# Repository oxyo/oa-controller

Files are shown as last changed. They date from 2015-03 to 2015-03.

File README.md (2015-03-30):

## Open Automation Wireless End-Point controller  



This is an Arduino UNO compatible device with 5 relay control channels and Real time clock.
It uses [Ciseco XRF wireless RF radio UART serial data module][] to communicate with Open Automation Center
This is a main controlling element in Open Automation system.  

It can be easily used to control devices like Heaters, Coolers, Fans, Fan Coils, Lights or any other
environment control device in your home.
  
For more information please visit [openautomation.center](http://openautomation.center)

Licensed under [WTFPL license terms](http://www.wtfpl.net/)

[Ciseco XRF wireless RF radio UART serial data module]: http://shop.ciseco.co.uk/xrf-wireless-rf-radio-uart-serial-data-module-xbee-shaped/

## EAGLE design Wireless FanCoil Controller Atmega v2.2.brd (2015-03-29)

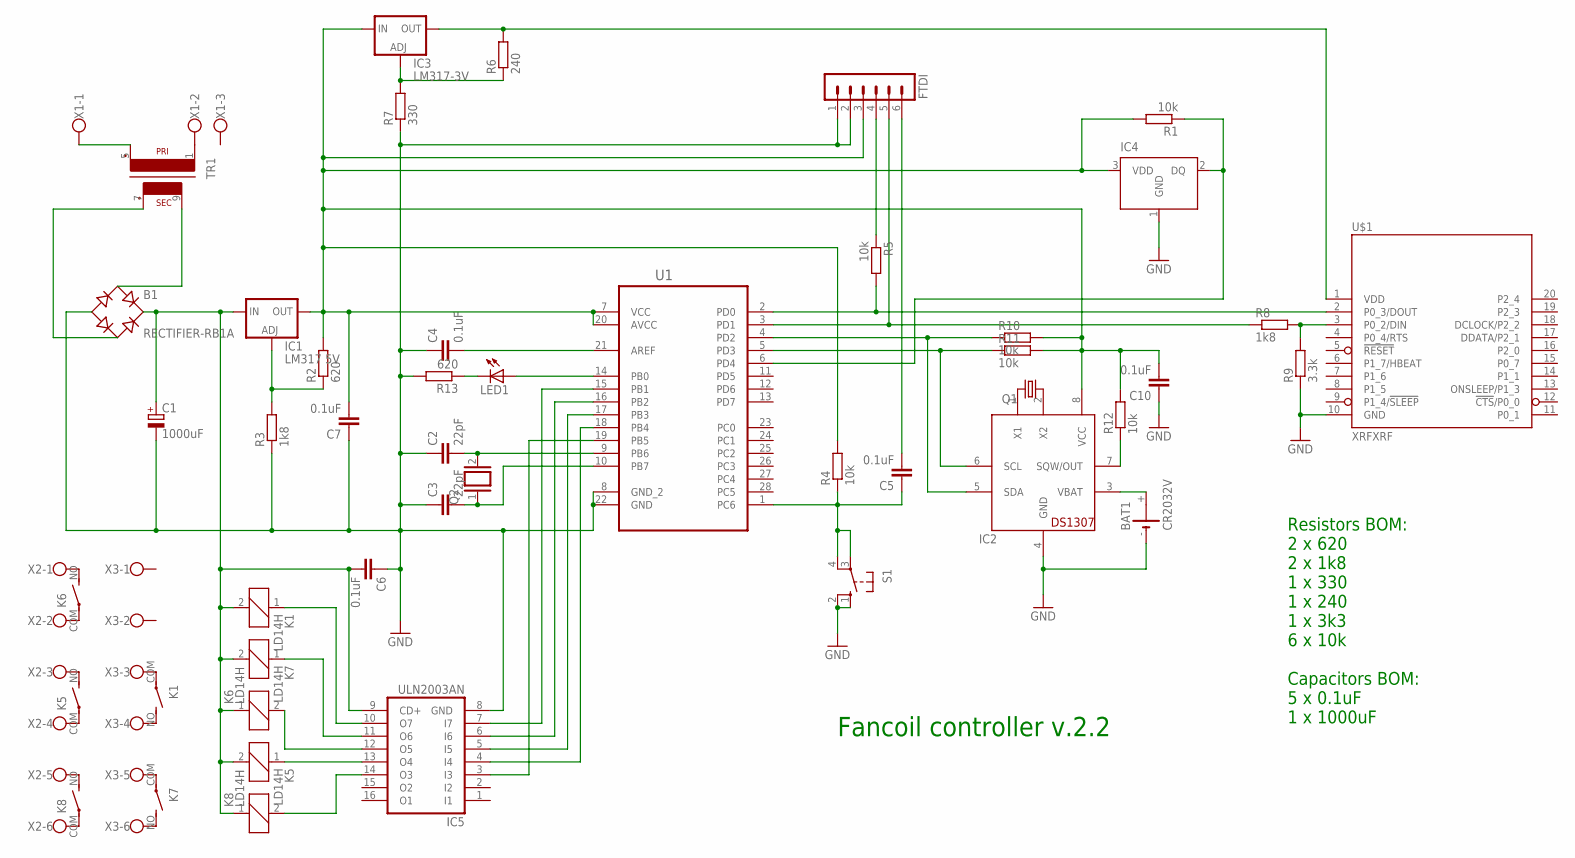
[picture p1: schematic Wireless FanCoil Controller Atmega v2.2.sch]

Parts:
B1: RECTIFIER-RB1A; RB1A
BAT1: CR2032V
C1: 1000uF; E5-10,5
C2, C3: 22pF; C025-025X050
C4, C5, C6, C7, C10: 0.1uF; C050-025X075
FTDI: MA06-1
IC1: LM317 5V; 317TS
IC2: DS1307; DIL08
IC3: LM317-3V; 317TS
IC4: DS1820; TO-92
IC5: ULN2003AN; DIL16
K1, K5, K6, K7, K8: LD14H; LD; MPN ALD112
LED1: LED3MM
Q1: CRYSTALTC26H; TC26H
Q2: XTAL/S; QS
R1, R4, R5, R10, R11, R12: 10k; 0207/5V
R2, R13: 620; 0207/5V
R3: 1k8; 0207/5V
R6: 240; 0207/5V
R7: 330; 0207/5V
R8: 1k8; 0207/12
R9: 3.3k; 0207/5V
S1: 10-XX; B3F-10XX
TR1: EI30-1
U1: ATMEGA328P-PU; DIP254P762X457-28
U$1: XRFXRF; XRF
X1: W237-103
X2, X3: W237-136

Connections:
GND: B1.-, BAT1.-, C1.-, C2.1, C3.1, C4.1, C6.1, C7.1, C10.1, FTDI.1, FTDI.2, IC2.4 (GND), IC4.1 (GND), IC5.8 (GND), R3.1, R7.1, R9.1, R13.2, S1.1 (S), S1.2 (S1), U1.8 (GND_2), U1.22 (GND), U$1.10 (GND)
LM317-5V: IC1.1 (ADJ), R2.1, R3.2
unnamed: C4.2, U1.21 (AREF)
unnamed: C5.2, FTDI.6
unnamed: IC2.2 (X2), Q1.1
unnamed: IC2.1 (X1), Q1.2
unnamed: IC5.10 (O7), K1.1
unnamed: IC3.2 (OUT), R6.2, U$1.1 (VDD)
unnamed: C7.2, C10.2, FTDI.3, IC1.2 (OUT), IC2.8 (VCC), IC3.3 (IN), IC4.3 (VDD), R1.2, R2.2, R4.2, R10.2, R11.2, R12.2, U1.7 (VCC), U1.20 (AVCC)
unnamed: TR1.1, X1.2
unnamed: TR1.5 (P2), X1.1
unnamed: B1.+, C1.+, C6.2, IC1.3 (IN), IC5.9 (CD+), K1.2, K5.2, K6.1, K7.2, K8.1
unnamed: B1.AC1, TR1.9 (S4)
unnamed: B1.AC2, TR1.7 (S3)
unnamed: C2.2, Q2.2, U1.9 (PB6)
unnamed: C3.2, Q2.1, U1.10 (PB7)
unnamed: C5.1, R4.1, S1.3, S1.4 (P1), U1.1 (PC6)
unnamed: FTDI.4, R5.1
unnamed: R5.2, U1.2 (PD0), U$1.2 (P0_3/DOUT)
unnamed: FTDI.5, R8.1, U1.3 (PD1)
unnamed: IC3.1 (ADJ), R6.1, R7.2
unnamed: IC2.5 (SDA), R10.1, U1.4 (PD2)
unnamed: R8.2, R9.2, U$1.3 (P0_2/DIN)
unnamed: IC2.6 (SCL), R11.1, U1.5 (PD3)
unnamed: IC2.7 (SQW/OUT), R12.1
unnamed: IC4.2 (DQ), R1.1, U1.6 (PD4)
unnamed: IC5.6 (I6), U1.16 (PB2)
unnamed: K8.NO (S), X2.5
unnamed: IC5.7 (I7), U1.15 (PB1)
unnamed: IC5.4 (I4), U1.18 (PB4)
unnamed: IC5.5 (I5), U1.17 (PB3)
unnamed: IC5.3 (I3), U1.19 (PB5)
unnamed: LED1.K (C), R13.1
unnamed: IC5.14 (O3), K8.2
unnamed: IC5.13 (O4), K5.1
unnamed: IC5.12 (O5), K6.2
unnamed: IC5.11 (O6), K7.1
unnamed: K8.COM, X2.6
unnamed: K5.NO (S), X2.3
unnamed: K5.COM, X2.4
unnamed: K6.NO (S), X2.1
unnamed: K6.COM, X2.2
unnamed: K7.COM, X3.5
unnamed: K7.NO (S), X3.6
unnamed: K1.COM, X3.3
unnamed: LED1.A, U1.14 (PB0)
unnamed: BAT1.+, IC2.3 (VBAT)
unnamed: K1.NO (S), X3.4

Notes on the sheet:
Fancoil controller v.2.2
Resistors BOM: 2 x 620 2 x 1k8 1 x 330 1 x 240 1 x 3k3 6 x 10k Capacitors BOM: 5 x 0.1uF 1 x 1000uF

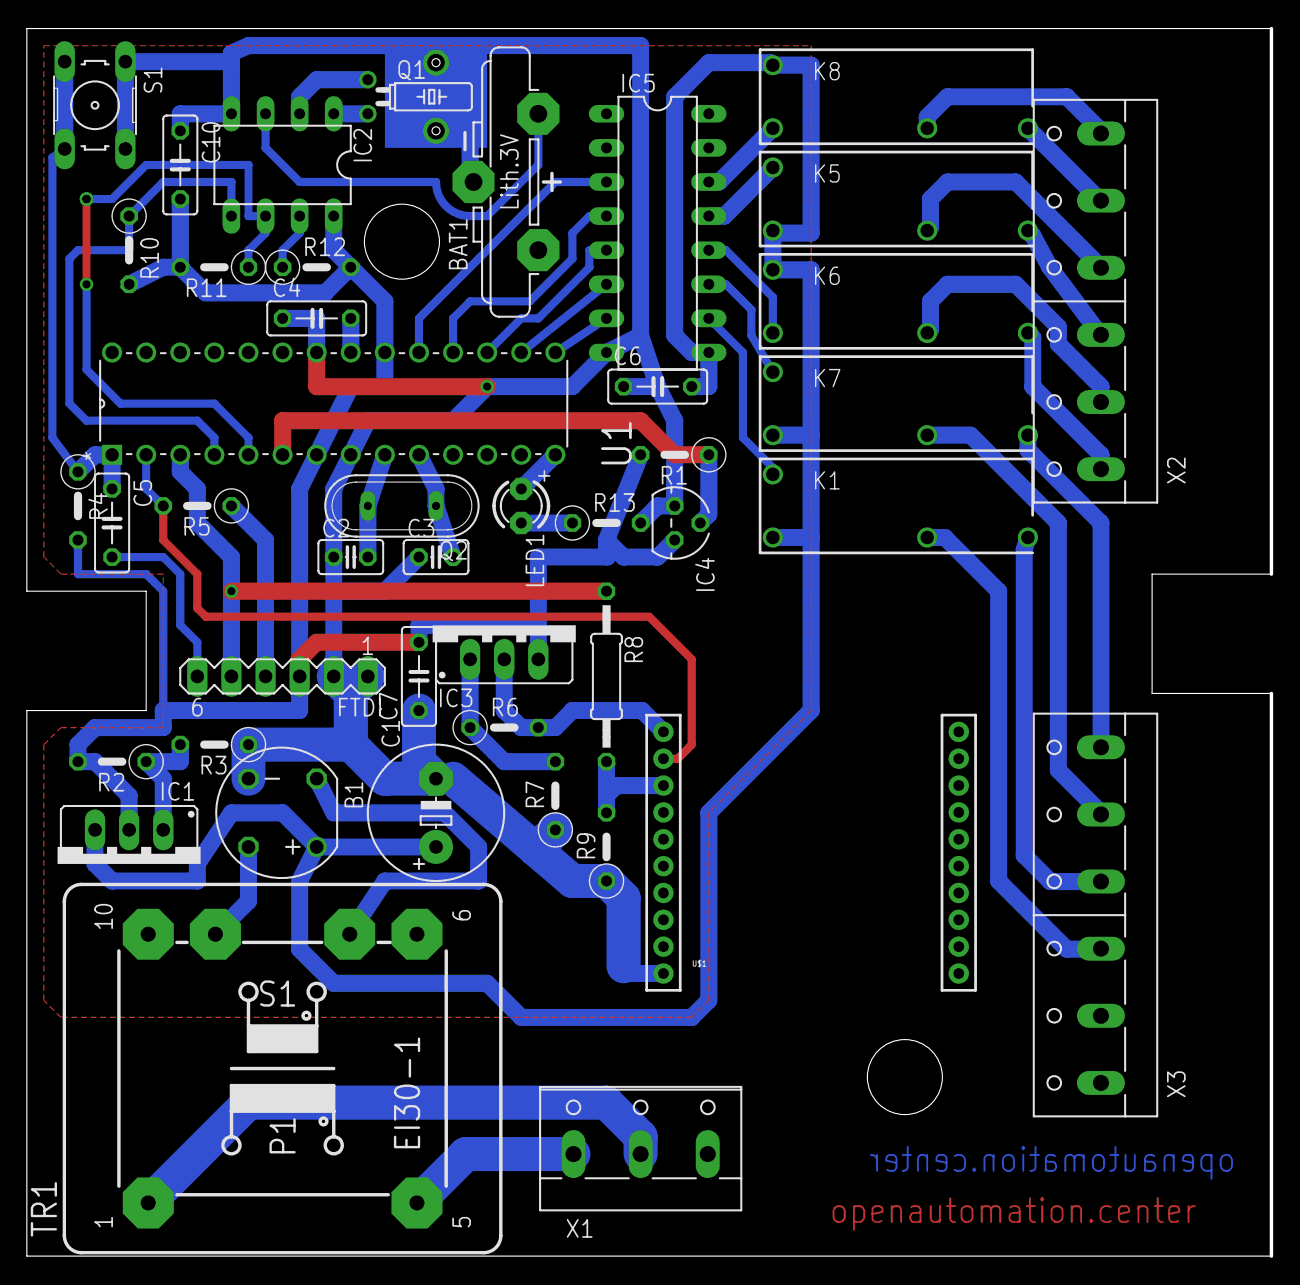
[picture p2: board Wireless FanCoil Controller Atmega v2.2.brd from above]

Board: 2 copper layers, 92.7 x 91.4 mm, 44 parts (0 on the bottom side), 48 nets.

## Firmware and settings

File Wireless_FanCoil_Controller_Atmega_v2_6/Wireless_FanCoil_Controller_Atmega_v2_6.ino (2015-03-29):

/*
 Smart Sensors Warm House controller code 
 Designed by V.Gudaitis oxyo@smartsensors.lt 2015 02 26
 
 RELEASE V.2.6 FEATURES
 
 * Code rewrited without Strings library
 * Minimal temperature bug fix
 * Weekend mode feature  
 * Remote reset feature
 * Remote diagnostics feature
 * Individual and broadcast command feature
 * Self-healing feature:
    - XRF reset (hardware change Arduino Pin5) if no sensor data received in 10 min. interval
    - Controller reset if no sensor data received 
    - Self disabling mode if no sensor data received
  
 
 Coordinator commands:
 01. R=0 - Fan speed set
 02. T=23.00 - Temperature to follow set 
 03. S=1 - Enabled/Disabled
 04. M=C - Cooling/Heating mode  
 05. O=01-23 - Offline hours set
 06. W=1 - weekend mode 
 
 Coordinator broadcast command example:
 aF0:R=4T=25.18S=1M=HA=1O=10-11W=0
 
 Individual Command example:
 aW3:R=4T=25.18S=1M=HA=1O=10-11W=0
 
 Service commands:
 06. aW0HI - Get status 
 07. aW0INFO - Get status (humman readable)
 08. aW0RESET - Controller reset
*/

#include <avr/wdt.h>
#include <EEPROM.h>
#include <DS1307.h>
#include <SPI.h>
#include <PString.h>

//Set Controller label >>>>>>>>>>>>>>>>>>>>>>>>>>>>>>>>>>>>>>>>>>>>>>>>>>>>>>>>>>>>>>>>>>>>>>>>

char ServiceName[3] = "W1"; //Controller ID
char CName[3] = "F1"; //Room label
char SNameT[3] = "T1"; //Temperature sensor to follow label

char CVER[] = "V.2.6"; //Firmware version info 
int maxCommandLength = 33; //Controller command length

//>>>>>>>>>>>>>>>>>>>>>>>>>>>>>>>>>>>>>>>>>>>>>>>>>>>>>>>>>>>>>>>>>>>>>>>>>>>>>>>>>>>>>>>>>>>>>

//Set random delay value for broadcast answers
int rDelay = 170;

//Define main control devices
int xrfReset = 5;
int led = 8;
int relay5 = 9;
int relay4 = 10;
int relay3 = 11;
int relay2 = 12;
int relay1 = 13;

//Rename main control devices for controller purpose
int heatingON = relay5;
int coolingON = relay4;
int fan1ON = relay3;
int fan2ON = relay2;
int fan3ON = relay1;

// Init the DS1307 RTC
DS1307_RAM ramBuffer;
DS1307 rtc(2, 3);
Time tObj;
int weekDay = 0;


char currentHourStr[8+1]; //temporary array for current hour string conversion to integer
char nonWorkStart[2+1]; //temporary array for nonWorkStart hour string conversion to integer
char nonWorkEnd[2+1];
int nonWorkStartHour;
int nonWorkEndHour;

//Controller temperature level set 
char tmpData[101]; //char array for wireless temperature sensor data
char tmpStr[5+1];
char tmp1Str[2+1];
char tmp2Str[2+1];
int tmp1Value;
int tmp2Value;
byte tmpDataIndex = 0;
char tempValueBuffer[6];
PString tempValue(tempValueBuffer, sizeof(tempValueBuffer)); // Variable to store Radio Sensor temperature value
float tempData_value = 0.00; //Temperature from wireless sensor
float tempData_set = 0.00; //Temperature to follow level (first time value)

//Controller mode initialisation
boolean coolingEnabled = false; //Cooling mode flag
boolean fancoilOFF = false; //Disabled mode flag
boolean nonWorkingTime = false; //Working Hour flag
boolean timerOFF = false; //Timer Off flag
char modeT = '*'; //Temperature control mode status
int fanSpeed; // Fan speed value 
boolean weekendMode = false; //Weekend mode current status
boolean enableWeekendMode = false; //Weekend mode enable flag


// Functions ========================================================================

void(* resetFunc) (void) = 0; //declare reset function @ address 0


void xrfToReset() {
  digitalWrite(xrfReset, LOW);    // turn the XRF off by making the voltage LOW  
  delay (500); 
  digitalWrite(xrfReset, HIGH);
  delay (500);  
} 

void shortLED(){
  
  digitalWrite(led, HIGH);   // turn the LED on (HIGH is the voltage level)
  delay (80);
  digitalWrite(led, LOW);    // turn the LED off by making the voltage LOW  
  delay (80);
  digitalWrite(led, HIGH);   
  delay (80);
  digitalWrite(led, LOW);     
}

void getDate(){ 
  Serial.print(rtc.getDateStr());
}

void getTime(){
  Serial.print(rtc.getTimeStr());
}

// Float to String conversion function ============================================
// Usage: floatToString(buffer string, float value, precision, minimum text width)

char * floatToString(char * outstr, double val, byte precision, byte widthp){
  char temp[16]; //increase this if you need more digits than 15
  byte i;
  temp[0]='\0';
  outstr[0]='\0';
  if(val < 0.0){
    strcpy(outstr,"-\0");  //print "-" sign
    val *= -1;
  }
  if( precision == 0) {
    strcat(outstr, ltoa(round(val),temp,10));  //prints the int part
  }
  else {
    unsigned long frac, mult = 1;
    byte padding = precision-1; 
    while (precision--)
      mult *= 10;
    val += 0.5/(float)mult;      // compute rounding factor    
    strcat(outstr, ltoa(floor(val),temp,10));  //prints the integer part without rounding
    strcat(outstr, ".\0"); // print the decimal point
    frac = (val - floor(val)) * mult;
    unsigned long frac1 = frac;
    while(frac1 /= 10)
      padding--;
    while(padding--)
      strcat(outstr,"0\0");    // print padding zeros
    strcat(outstr,ltoa(frac,temp,10));  // print fraction part
  }

  // generate width space padding
  if ((widthp != 0)&&(widthp >= strlen(outstr))){
    byte J=0;
    J = widthp - strlen(outstr);
    for (i=0; i< J; i++) {
      temp[i] = ' ';
    }
    temp[i++] = '\0';
    strcat(temp,outstr);
    strcpy(outstr,temp);
  }
  return outstr;
}

// Fan speed set function =======================================================
void fanSpeedSet(int fanSpeed){ 
  
  if (fanSpeed == 0) {
       digitalWrite(fan1ON, LOW);
       digitalWrite(fan2ON, LOW);
       digitalWrite(fan3ON, LOW);
  }  
  if (fanSpeed == 1) {
       digitalWrite(fan1ON, HIGH);
       digitalWrite(fan2ON, LOW);
       digitalWrite(fan3ON, LOW);
  } 
  if (fanSpeed == 2) {
       digitalWrite(fan1ON, LOW);
       digitalWrite(fan2ON, HIGH);
       digitalWrite(fan3ON, LOW);
  } 
  if (fanSpeed == 3) {
       digitalWrite(fan1ON, LOW);
       digitalWrite(fan2ON, LOW);
       digitalWrite(fan3ON, HIGH);
  }    
  
}



//===============================================  SETUP  ==================================================
void setup() { 
        
  // Set the clock to run-mode
  rtc.halt(false);
  
  //Time set routine
  // The following lines can be commented out to use the values already stored in the DS1307
  //rtc.setTime(13, 41, 0);    // Set the time to 12:00:00 (24hr format)
  //rtc.setDate(13, 06, 2014);  // Set the date to April 02, 2013
  //rtc.setDOW(FRIDAY);        // Set Day-of-Week 
   //MONDAY	1
   //TUESDAY	2
   //WEDNESDAY	3
   //THURSDAY	4
   //FRIDAY	5
   //SATURDAY	6
   //SUNDAY	7
  
  pinMode(xrfReset, OUTPUT);
  pinMode(led, OUTPUT);
  pinMode(relay1, OUTPUT);  
  pinMode(relay2, OUTPUT); 
  pinMode(relay3, OUTPUT); 
  pinMode(relay4, OUTPUT); 
  pinMode(relay5, OUTPUT); 
  
  //LED Indication
  shortLED();  
  delay(100);
  shortLED();
  
  digitalWrite(xrfReset, HIGH);    
  
  // Setup Serial connection
  Serial.begin(1200);
  delay(1000);
    
  //Printing controller header   

  if (EEPROM.read(777) == 199) {
    Serial.print(" ");
    Serial.print(ServiceName);
    Serial.print(" ");    
    Serial.print(CName);    
    Serial.print(" OFF! ");
    Serial.print(CVER);    
    Serial.println();    
  }  
  if (EEPROM.read(777) == 200) {
    Serial.println(); 
    Serial.print(ServiceName);
    Serial.print(" ");
    Serial.print(CName);
    Serial.print(" ON ");
    Serial.print(CVER);    
    Serial.println();
  }
      
  //Initialise WDT
  wdt_enable(WDTO_8S);  //Set up the watchdog timer.  
  wdt_reset(); 
}



//===============================================  MAIN  ==================================================
void loop() {
   
  wdt_reset(); //Reset watchdog timer
  
  //Check weekday =================================================
  tObj = rtc.getTime();
  weekDay = tObj.dow;

  
  //Get Current time
  int currentHour = tObj.hour;
  int currentMin = tObj.min;
  int currentSec = tObj.sec;
  
  char currentHour_[3], currentMin_[3], currentSec_[3];
  PString currentHour_S(currentHour_, sizeof(currentHour_)); 
  PString currentMin_S(currentMin_, sizeof(currentMin_)); 
  PString currentSec_S(currentSec_, sizeof(currentSec_)); 
  
  currentHour_S.print(currentHour);
  currentMin_S.print(currentMin);
  currentSec_S.print(currentSec);  
  

  //Check weekend mode ============================================
  weekendMode = false;
  if(enableWeekendMode){
      if (weekDay == 6 || weekDay == 7) weekendMode = true; 
  } 
   
  //Check fan speed value =========================================
  fanSpeed = EEPROM.read(601);
  
  //Check working mode ============================================
  if(EEPROM.read(999) == 1){
      coolingEnabled = false; //Heating mode
  } else {
      coolingEnabled = true; //Cooling mode
  }  
   
  //Check Offline hours ===========================================
    //currentHourStr[0] = rtc.getTimeStr()[0];
    //currentHourStr[1] = rtc.getTimeStr()[1]; 
    //int currentHour = atoi(currentHourStr);
    
    int offlineHourStart = EEPROM.read(40);
    int offlineHourEnd = EEPROM.read(50);
    
    if (currentHour >= offlineHourStart) nonWorkingTime = true;
    if (currentHour + 1 >= offlineHourEnd) nonWorkingTime = false;

    
  // Check Offline hours mode Off Flag =============================================       
    if(EEPROM.read(555) == 200) {
      timerOFF == true;
      nonWorkingTime = false;   
    } else {
      timerOFF == false;    
    } 
  
  //Check if Fancoil is not disabled ==============================
    if (EEPROM.read(777) == 199){
      fancoilOFF = true;      
    } else {
      fancoilOFF = false;
    }
         
  
  //Getting last temperature sensor value from RAM
   char t_Old[5];
   t_Old[0] = rtc.peek(6);
   t_Old[1] = rtc.peek(7);
   t_Old[2] = rtc.peek(8);
   t_Old[3] = rtc.peek(9);
   t_Old[4] = rtc.peek(10);

   float tempData_Old = atof(t_Old); 
   
   int oldMin = rtc.peek(25);
   int deltaMin = currentMin - oldMin;
   
   unsigned int resetCounter = rtc.peek(27);
        
   if ( abs(deltaMin) > 10 ) { // if TX not received since 6 min
     xrfToReset();     
     rtc.poke(25, currentMin); //reset TX received time
     rtc.poke(27, resetCounter + 1); //reset counter 
     Serial.println();
     Serial.print(ServiceName);
     Serial.print(" > ");
     Serial.print(SNameT);
     Serial.print(" DEAD");   
     Serial.print(resetCounter);
     fancoilOFF = true; 
     //resetFunc(); //reset controller
     
     // If no response from T sensor after few XRF resets > reset fanCoil 
     if (resetCounter > 2) resetFunc(); //reset controller
   }
  
   // If no response from T sensor long time ago > disable controller 
   if (resetCounter > 3) {
       fancoilOFF = true; 
       //rtc.poke(27, 0); //reset counter
   }

   //Getting temperature to follow =======================================
  
   if (weekendMode) tempData_set = tempData_set - 3; 
   
 
  //Environment control routine =========================================
  
  if (!fancoilOFF) {
    
      if (timerOFF) {
        
          if (tempData_set > tempData_value && !coolingEnabled){
               modeT = 'T';  //Heating active state        
               digitalWrite(coolingON, LOW);      
               digitalWrite(heatingON, HIGH);       
               if (fanSpeed == 4) {
                 digitalWrite(fan1ON, HIGH);
                 digitalWrite(fan2ON, LOW);
                 digitalWrite(fan3ON, LOW); 
               } else {
                  fanSpeedSet(fanSpeed);      
               }         
                    
          } else if (tempData_set < tempData_value && !coolingEnabled){ 
               modeT = 't'; //Heating passive state
               digitalWrite(coolingON, LOW); 
               digitalWrite(heatingON, LOW); 
               if (fanSpeed == 4) {
                 digitalWrite(fan1ON, LOW);
                 digitalWrite(fan2ON, LOW); 
                 digitalWrite(fan3ON, LOW);
               } else {
                  fanSpeedSet(fanSpeed);      
               }                  
          }    
         
          if (tempData_set > tempData_value && coolingEnabled){
               modeT = 'c';  //Cooling passive state        
               digitalWrite(coolingON, LOW);      
               digitalWrite(heatingON, LOW);       
               if (fanSpeed == 4) {
                 digitalWrite(fan1ON, LOW);
                 digitalWrite(fan2ON, LOW);
                 digitalWrite(fan3ON, LOW); 
               } else {
                  fanSpeedSet(fanSpeed);      
               }         
                    
          } else if (tempData_set < tempData_value && coolingEnabled){ 
               modeT = 'C'; //Cooling active state
               digitalWrite(coolingON, HIGH); 
               digitalWrite(heatingON, LOW); 
               if (fanSpeed == 4) {
                 digitalWrite(fan1ON, HIGH);
                 digitalWrite(fan2ON, LOW); 
                 digitalWrite(fan3ON, LOW);
               } else {
                  fanSpeedSet(fanSpeed);      
               }                  
          }          
        
           
      } else { 
       
          if (tempData_set > tempData_value && !coolingEnabled && !nonWorkingTime){
               modeT = 'T';  //Heating active state              
               digitalWrite(coolingON, LOW);      
               digitalWrite(heatingON, HIGH);       
               if (fanSpeed == 4) {
                 digitalWrite(fan1ON, HIGH);
                 digitalWrite(fan2ON, LOW);
                 digitalWrite(fan3ON, LOW); 
               } else {
                  fanSpeedSet(fanSpeed);      
               }  
                    
          } else if (tempData_set < tempData_value && !coolingEnabled && !nonWorkingTime){ 
               modeT = 't'; //Heating passive state
               digitalWrite(coolingON, LOW); 
               digitalWrite(heatingON, LOW); 
               if (fanSpeed == 4) {
                 digitalWrite(fan1ON, LOW);
                 digitalWrite(fan2ON, LOW); 
                 digitalWrite(fan3ON, LOW);
               } else {
                  fanSpeedSet(fanSpeed);      
               } 
               
          } else if (tempData_set > tempData_value && coolingEnabled && !nonWorkingTime){ 
               modeT = 'c';  //Cooling passive state        
               digitalWrite(coolingON, LOW);      
               digitalWrite(heatingON, LOW);       
               if (fanSpeed == 4) {
                 digitalWrite(fan1ON, LOW);
                 digitalWrite(fan2ON, LOW);
                 digitalWrite(fan3ON, LOW); 
               } else {
                  fanSpeedSet(fanSpeed);      
               } 
               
          } else if (tempData_set < tempData_value && coolingEnabled && !nonWorkingTime){ 
               modeT = 'C'; //Cooling active state
               digitalWrite(coolingON, HIGH); 
               digitalWrite(heatingON, LOW); 
               if (fanSpeed == 4) {
                 digitalWrite(fan1ON, HIGH);
                 digitalWrite(fan2ON, LOW); 
                 digitalWrite(fan3ON, LOW);
               } else {
                  fanSpeedSet(fanSpeed);      
               }                          
    
                                
          } else if (nonWorkingTime) {
               modeT = 'o'; //Disabled Off hours state
               digitalWrite(coolingON, LOW); 
               digitalWrite(heatingON, LOW); 
               digitalWrite(fan3ON, LOW);
               digitalWrite(fan2ON, LOW);
               digitalWrite(fan1ON, LOW);       
          } 
    
      }
      
  } else {
  
       modeT = 'D'; //Disabled state
       digitalWrite(coolingON, LOW); 
       digitalWrite(heatingON, LOW); 
       digitalWrite(fan3ON, LOW);
       digitalWrite(fan2ON, LOW);
       digitalWrite(fan1ON, LOW);    
  }
  
 //Coordinator routine ======================================================================
    
  // Check if there's incoming serial data.
  if (Serial.available() > 0) {
    char incomingByte = Serial.read();

    // Checks for termination of the string.
    if (incomingByte == 'a') {
      
      char serialData[maxCommandLength];
      int number_of_bytes_received;
      number_of_bytes_received = Serial.readBytesUntil(13, serialData, maxCommandLength - 1);
      serialData[number_of_bytes_received] = '\0';

      //0. Getting wireless temperature sensor value  ======================================      
      if (serialData[0] == SNameT[0] && serialData[1] == SNameT[1] && serialData[2] == 'T' && serialData[3] == 'M' && serialData[4] == 'P' && serialData[5] == 'A') {         
          tmpData[tmpDataIndex++] = serialData[6];
          rtc.poke(6,serialData[6]);
          tmpData[tmpDataIndex++] = serialData[7];
          rtc.poke(7,serialData[7]);
          tmpData[tmpDataIndex++] = serialData[8];
          rtc.poke(8,serialData[8]);
          tmpData[tmpDataIndex++] = serialData[9];
          rtc.poke(9,serialData[9]);          
          tmpData[tmpDataIndex++] = serialData[10]; 
          rtc.poke(10,serialData[10]); 
          tempData_value = atof(tmpData);                   
          tmpDataIndex = 0;          
          //rtc.poke(24,currentHour);
          rtc.poke(25, tObj.min); 
          rtc.poke(27, 0); // reset reseting counter
          fancoilOFF = false;
          modeT = '*';
      } 
 
 
      // 1.Getting Coordinator Command ======================================================= 
      if ( serialData[0] == CName[0] && serialData[1] == CName[1] && serialData[2] == ':') { 
      
        char serialCommand[maxCommandLength - 4];

        for (int i=0; i< maxCommandLength; i++) {
           serialCommand[i] = serialData[i+3];
        }        

        serialCommand[29] = '\0';
                
        //1.0. Fan Speed set to auto --------------------------------------------------------------
        if (serialCommand[0] == 'R' && serialCommand[1] == '=' && serialCommand[2] == '0') {          
           if(EEPROM.read(601) != 0) EEPROM.write(601, 0);  //Fan speed set to 0 - OFF mode
           //fanSpeedSet(0);
        }  
        
        //1.1. Fan Speed set to 1 -----------------------------------------------------------------
        if (serialCommand[0] == 'R' && serialCommand[1] == '=' && serialCommand[2] == '1') {          
           if(EEPROM.read(601) != 1) EEPROM.write(601, 1);  //Fan speed set to 1 
           //fanSpeedSet(1);         
        }
        
        //1.2. Fan Speed set to 2 -----------------------------------------------------------------
         if (serialCommand[0] == 'R' && serialCommand[1] == '=' && serialCommand[2] == '2') {          
           if(EEPROM.read(601) != 2) EEPROM.write(601, 2);  //Fan speed set to 2
           //fanSpeedSet(2);          
        }
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
